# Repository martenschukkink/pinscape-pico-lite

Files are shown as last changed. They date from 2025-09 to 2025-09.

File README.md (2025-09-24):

# How-to: "Lite" Virtual Pinball setup with a Pinscape Pico

>  Note that this is a work in progress. I am currently testing v1 of the board. The updated v1.1 board contains a small fix to the layout and should work, but this project comes with NO WARRANTIES.

This page documents how to build a basic input controller that can be used in a Virtual Pinball cabinet that supports buttons, nudging and a plunger.

The board is based on the great work of Michael J Roberts aka MJR, who developed the [Pinscape Pico](https://github.com/mjrgh/PinscapePico/) I/O controller for pinball cabinets.

This project supports connecting almost all necessary pinball related buttons. It also supports nudging through the Adafruit MMA8451 breakout board and uses the Adafruit ADS1115 breakout board to connect an analog plunger with a potentiometer.

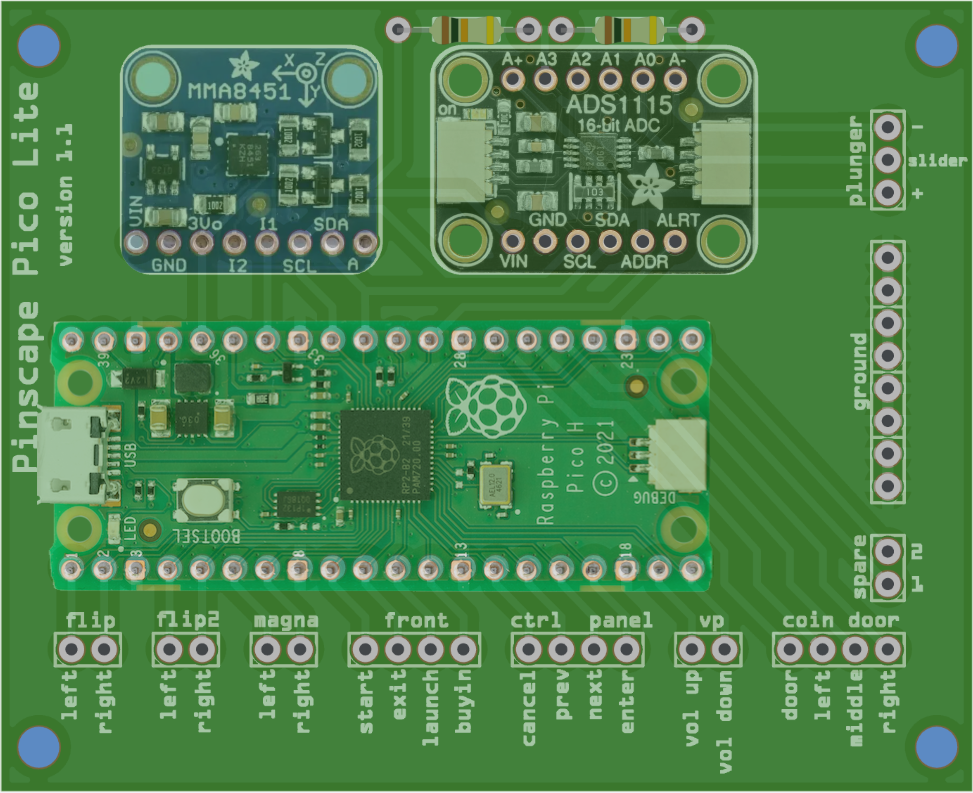
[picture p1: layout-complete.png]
Complete layout


This project is meant as a Virtual Pinball setup without outputs, hence the "Lite". If you need outputs, this project might not be for you. 

## Materials and tools needed

### Materials

- PCB, designed for this project ([Fritzing design](<Pinscape Pico Lite.fzz>))
- Raspberry Pi Pico H ([Raspberry Pi](https://www.raspberrypi.com/documentation/microcontrollers/pico-series.html#pico-1-family), [DigiKey](https://www.digikey.nl/nl/products/detail/raspberry-pi/SC0917/16608257))
- Adafruit MMA8451 Triple-Axis Accelerometer ([Adafruit #2019](https://www.adafruit.com/product/2019), [DigiKey](https://www.digikey.nl/nl/products/detail/adafruit-industries-llc/2019/4990790))
- Adafruit ADS1115 16-Bit ADC ([Adafruit #1085](https://www.adafruit.com/product/1085), [DigiKey](https://www.digikey.nl/nl/products/detail/adafruit-industries-llc/1085/5761229))
- Analog plunger kit ([GermanGamingSupplies](https://germangamingsupplies.com/Analog-Plunger-Set), [Arnoz](https://shop.arnoz.com/en/19-plunger))
- 2x 10kΩ resistor
- Misc. pins and connectors (optional)
- Solder

There is a [Bill of Materials](BOM.csv) that can be used for ordering (DigiKey part numbers are included). This excludes the plunger kit.

### Tools

- Soldering station
- Third hand soldering station (preferable)

## Creating the board

The image below shows the layout of the PCB. The PCB is designed in [Fritzing](https://fritzing.org/) and the file can be downloaded here: [Pinscape Pico Lite.fzz](<Pinscape Pico Lite.fzz>) The PCB can be easily ordered at Aisler.net, by uploading the Fritzing file there from the software or on their website.

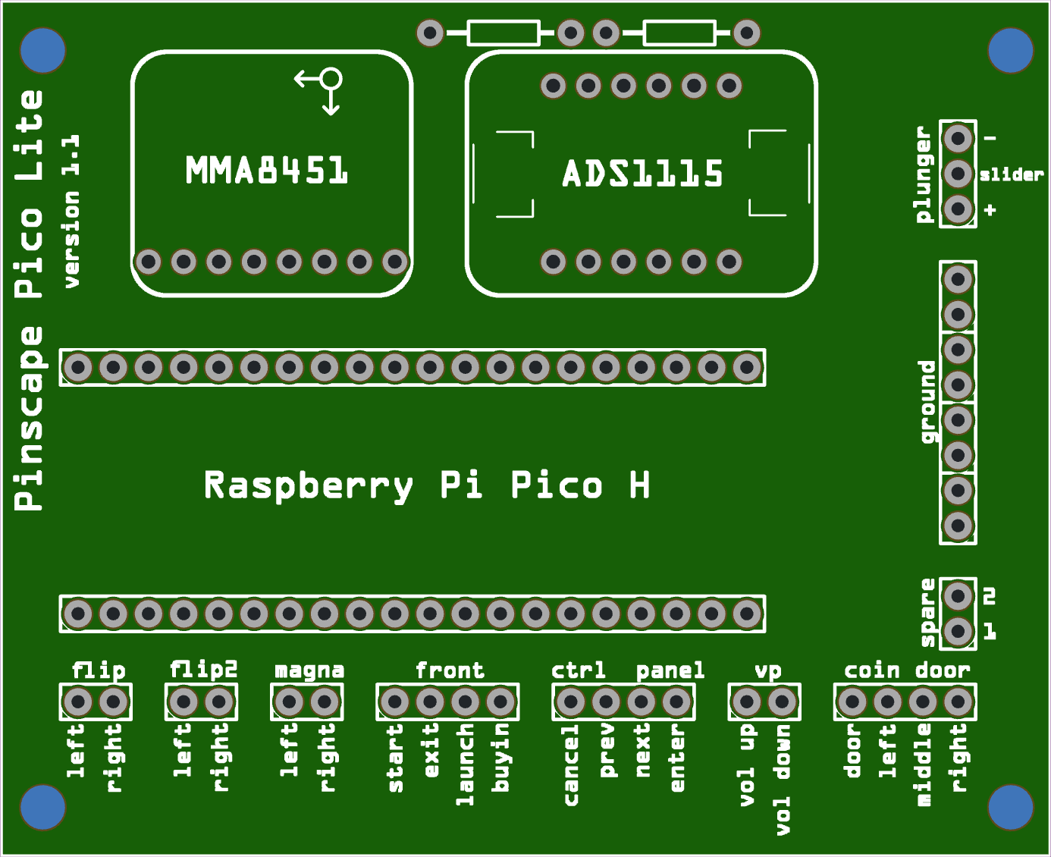
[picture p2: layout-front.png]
PCB frontside

Frontside view (solder components here)

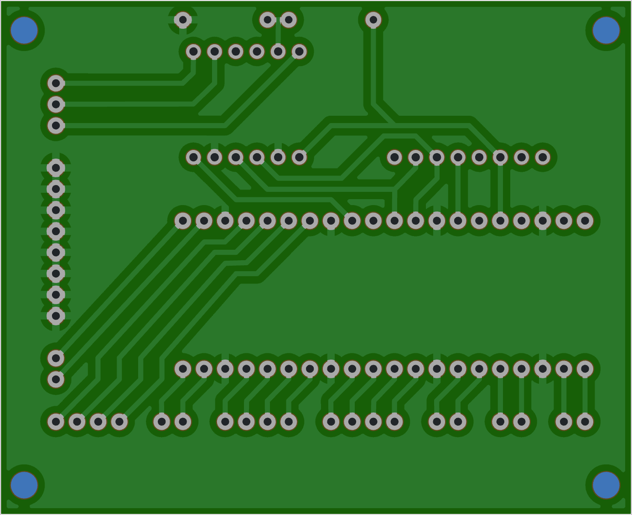
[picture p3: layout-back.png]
PCB backside

Backside view (for reference only)

### Placing the Raspberry Pi Pico H, MMA8451 and ADS1115
1. Solder the pin headers included in the package to the MMA8451 and the ADS1115
1. Solder the two 10kΩ resistors at the marked location
1. Solder the Raspberry Pi Pico H at the marked location
1. Solder the MMA8451 at the marked location
1. Solder the ADS1115 at the marked location

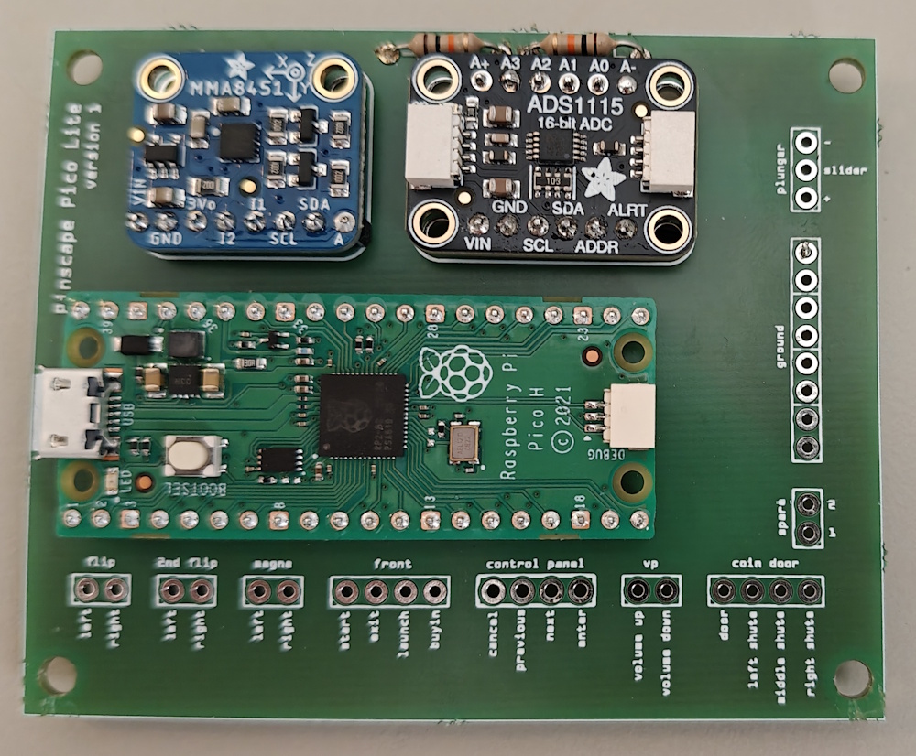
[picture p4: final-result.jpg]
final result


### Connecting the buttons and plunger
Soldering pin headers to the PCB and using connectors for the button and plunger wires is optional. Alternatively, you can solder the wires for buttons and plunger directly to the board. For the small additional cost, I would advice on purchasing the pins and connectors from the parts list.

### Software configuration

1. Download the [latest Pinscape Pico release](https://github.com/mjrgh/PinscapePico/releases) and unzip it.
1. Start the GUIConfigTool, connect the Pico and install the latest firmware (it's included in the same directory).
1. Copy the text from [config.json](config.json) and paste it in the configuration tab of the GUIConfigTool (replacing the existing text).
1. Click the "Program Pico" button. The Pinscape Pico is rebooted with the new configuration. You can check the Buttons, Nudge and Plunger tabs to see if everything works correctly, tweak the nudge settings and calibrate the plunger.

You now should be all set to use the Pinscape Pico as a Virtual Pinball controller. 

## Background information

Below you will find the button and breakout board connections to the Raspberry Pi Pico / Pinscape Pico. The configuration in the [config.json](config.json) file is based on this layout. If you change something in the layout, the config file should be updated accordingly.
 
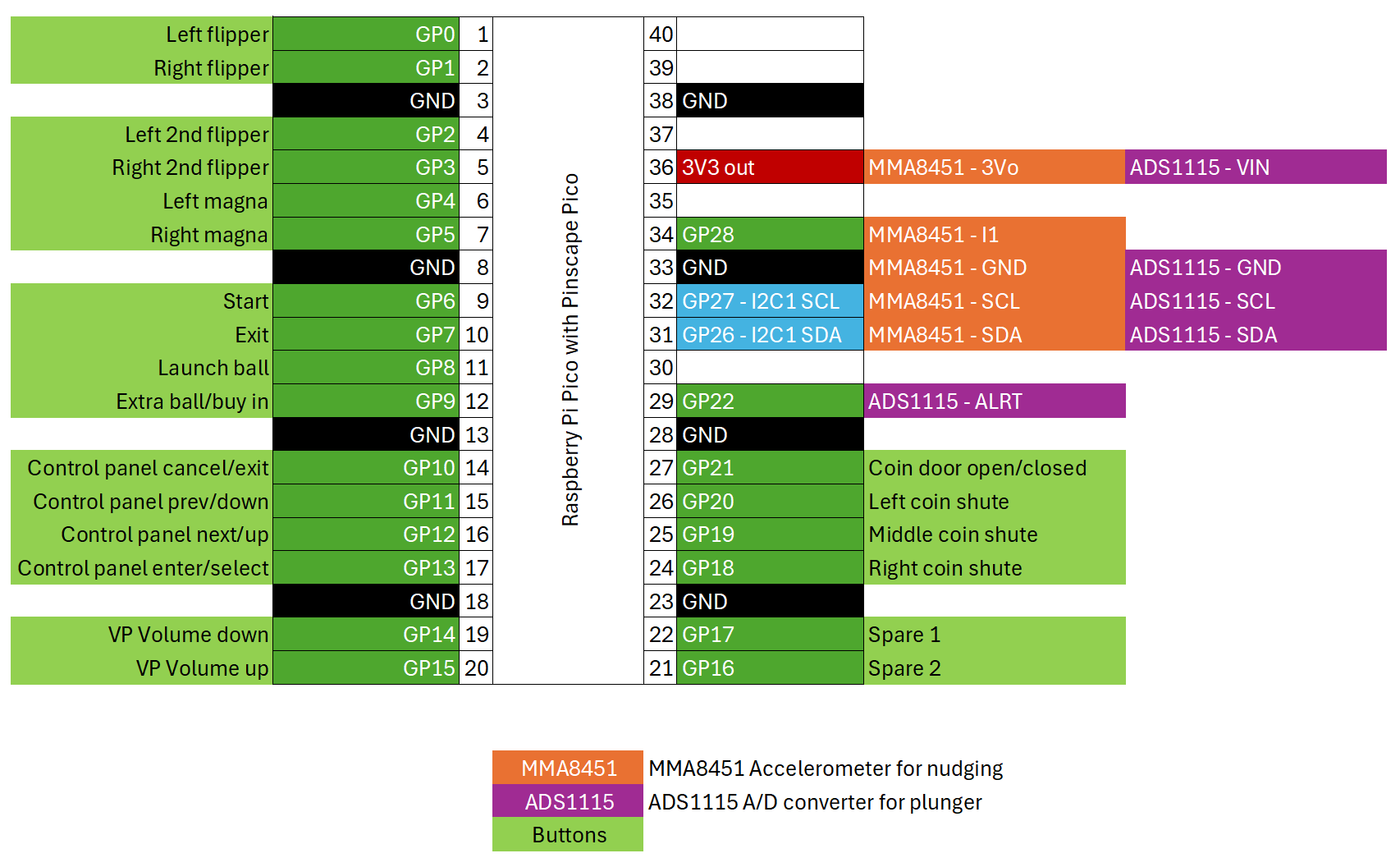
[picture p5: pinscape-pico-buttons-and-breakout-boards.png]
Pinscape Pico: buttons and breakout boards


## License
Copyright 2025, Marten Schukkink

Released under a [BSD 3-clause license - NO WARRANTY](LICENCE)

## Credits and links

- A big shoutout to Michael J Roberts aka MJR for creating the original Pinscape, the [Pinscape Pico](https://github.com/mjrgh/PinscapePico/), the [PinballY frontend](http://mjrnet.org/pinscape/PinballY.php) and [The New Pinscape Build Guide](http://mjrnet.org/pinscape/BuildGuideV2/BuildGuide.php).
- Use and configuration of the MMA8451Q
  - [adafruit.com &rarr; Adafruit MMA8451 Accelerometer Breakout](https://learn.adafruit.com/adafruit-mma8451-accelerometer-breakout)
  - [mjr github &rarr; MMA8451Q Setup Guide](https://github.com/mjrgh/PinscapePico/blob/main/Guides/MMA8451Q-Setup.md)
  - [mjrnet.org &rarr; JSON Configuration Reference &rarr; MMA8451Q Accelerometer](http://mjrnet.org/pinscape/PinscapePico/Help/JSONConfigRef.htm#mma8451q)

- Use and configuration of the ADS1115
  - [adafruit.com &rarr; Adafruit 4-Channel ADC Breakouts](https://learn.adafruit.com/adafruit-4-channel-adc-breakouts)
  - [mjr github &rarr; Pinscape Pico - DIY-Friendly Expansion Board &rarr; ADS1115 ADC](https://github.com/mjrgh/PinscapePico/tree/main/ExpansionBoards/DIY-Friendly#ads1115-adc)
  - [mjrnet.org &rarr; JSON Configuration Reference &rarr; ADS1115 ADC](http://mjrnet.org/pinscape/PinscapePico/Help/JSONConfigRef.htm#ads1115)

## Updates

### Version 1.1
- Fixed ground fill in PCB design not actually connected to GND which caused ADS1115 to not be properly grounded
- Increased size of texts on PCB for better readability

### Version 1.0
- First version of PCB, based on breadboard prototype

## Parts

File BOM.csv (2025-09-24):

Manufacturer Part Number | Manufacturer Name | Description | Quantity | Digi-Key Part Number
SC0917 | Raspberry Pi | RASPBERRY PI PICO H RP2040 | 1 | 2648-SC0917-ND
2019 | Adafruit Industries LLC | MMA8451 3AXIS ACCEL BREAKOUT BRD | 1 | 1528-1041-ND
1085 | Adafruit Industries LLC | ADS1115 16BIT ADC 4CH PROG GAIN | 1 | 1528-1085-ND
0022232021 | Molex | CONN HEADER VERT 2POS 2.54MM | 10 | 900-0022232021-ND
0022012027 | Molex | CONN RCPT HSG 2POS 2.54MM | 10 | WM2011-ND
0022232031 | Molex | CONN HEADER VERT 3POS 2.54MM | 1 | WM4201-ND
0022012037 | Molex | CONN RCPT HSG 3POS 2.54MM | 1 | WM2012-ND
0022232041 | Molex | CONN HEADER VERT 4POS 2.54MM | 3 | WM4202-ND
0022012047 | Molex | CONN RCPT HSG 4POS 2.54MM | 3 | 900-0022012047-ND
CF14JT10K0 | Stackpole Electronics Inc | RES 10K OHM 5% 1/4W AXIAL | 2 | CF14JT10K0CT-ND
0008500113 | Molex | CONN 22-30AWG CRIMP TIN | 100 | WM1114CT-ND

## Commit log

2025-09-06 Initial PCB design and How-to.
    [Pinscape Pico Lite.fzz, parts.csv]
2025-09-06 Update Fritzing design, move ALRT to GP22
    [Pinscape Pico Lite.fzz]
2025-09-07 Update config to match prototype and PCB design
2025-09-08 Update and rename files
    [BOM.csv]
2025-09-19 Version 1.1: PCB ground fix and text sizing
    [Pinscape Pico Lite.fzz]
2025-09-24 Simplify BOM and update of readme
    [BOM.csv]
